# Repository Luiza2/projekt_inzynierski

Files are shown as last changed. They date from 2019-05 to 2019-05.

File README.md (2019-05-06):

Postępy realizacji pracy inżynierskiej.
Temat: Prędkościomierz z GPS i układem akwizycji danych.

Wykorzystane elementy:
- STM32 NUCLEO-F446RE
- wyświetlacz OLED niebieski graficzny 1,3'' 128x64px SPI
- moduł GPS NEO-7M-C (B) 
- moduł czytnika kart microSD
- moduł bluetooth HC-05
- własna płytka PCB (w opracowaniu)

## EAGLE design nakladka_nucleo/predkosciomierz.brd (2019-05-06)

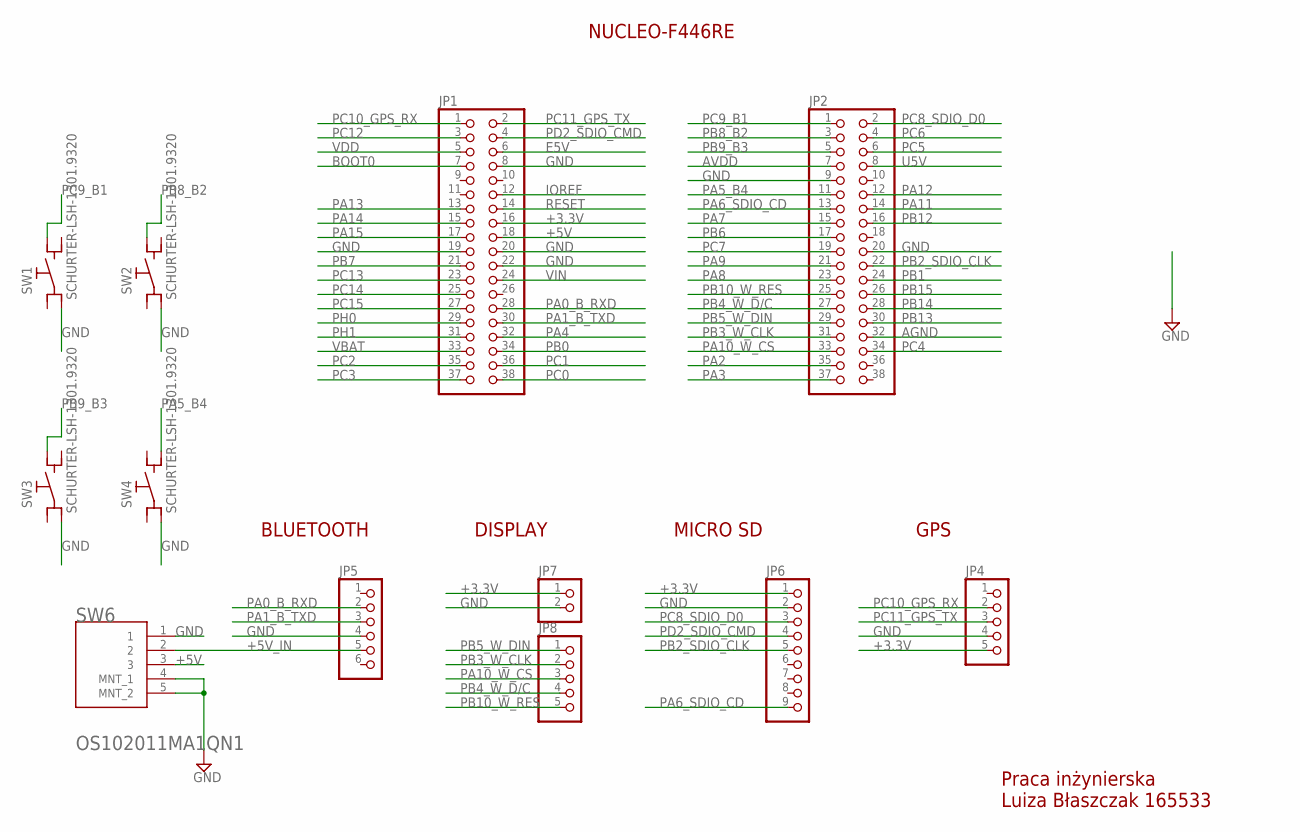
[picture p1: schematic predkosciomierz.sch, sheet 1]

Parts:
JP1, JP2: PINHD-2X19; 2X19
JP4, JP8: PINHD-1X5; 1X05
JP5: PINHD-1X6; 1X06
JP6: PINHD-1X9; 1X09
JP7: PINHD-1X2; 1X02
SW1, SW2, SW3, SW4: SCHURTER-LSH-1301.9320; LSH
SW6: C&K_OS102011MA1QN1C&K_OS102011MA1QN1_0_0; C&K_OS102011MA1QN1_0

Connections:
+3.3V: JP1.16, JP4.5, JP6.1, JP7.1
+5V: JP1.18, SW6.3
+5V_IN: JP5.5, SW6.2
AGND: JP2.32
AVDD: JP2.7
BOOT0: JP1.7
E5V: JP1.6; also elsewhere on the board
GND: JP1.8, JP1.19, JP1.20, JP1.22, JP2.9, JP2.20, JP4.4, JP5.4, JP6.2, JP7.2, SW1.C2 (C), SW2.C2 (C), SW3.C2 (C), SW4.C2 (C), SW6.1, SW6.4 (MNT_1), SW6.5 (MNT_2); also elsewhere on the board
IOREF: JP1.12
PA0_B_RXD: JP1.28, JP5.2
PA1_B_TXD: JP1.30, JP5.3
PA2: JP2.35
PA3: JP2.37
PA4: JP1.32
PA5_B4: JP2.11, SW4.NO2 (NO)
PA6_SDIO_CD: JP2.13, JP6.9
PA7: JP2.15
PA8: JP2.23
PA9: JP2.21
PA10_W_CS: JP2.33, JP8.3
PA11: JP2.14
PA12: JP2.12
PA13: JP1.13
PA14: JP1.15
PA15: JP1.17
PB0: JP1.34
PB1: JP2.24
PB2_SDIO_CLK: JP2.22, JP6.5
PB3_W_CLK: JP2.31, JP8.2
PB4_W_D/C: JP2.27, JP8.4
PB5_W_DIN: JP2.29, JP8.1
PB6: JP2.17
PB7: JP1.21
PB8_B2: JP2.3, SW2.NO1 (NO)
PB9_B3: JP2.5, SW3.NO1 (NO)
PB10_W_RES: JP2.25, JP8.5
PB12: JP2.16
PB13: JP2.30
PB14: JP2.28
PB15: JP2.26
PC0: JP1.38
PC1: JP1.36
PC2: JP1.35
PC3: JP1.37
PC4: JP2.34
PC5: JP2.6
PC6: JP2.4
PC7: JP2.19
PC8_SDIO_D0: JP2.2, JP6.3
PC9_B1: JP2.1, SW1.NO1 (NO)
PC10_GPS_RX: JP1.1, JP4.2
PC11_GPS_TX: JP1.2, JP4.3
PC12: JP1.3
PC13: JP1.23
PC14: JP1.25
PC15: JP1.27
PD2_SDIO_CMD: JP1.4, JP6.4
PH0: JP1.29
PH1: JP1.31
RESET: JP1.14
U5V: JP2.8
VBAT: JP1.33
VDD: JP1.5
VIN: JP1.24

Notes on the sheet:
DISPLAY
MICRO SD
GPS
NUCLEO-F446RE
BLUETOOTH
Praca inżynierska Luiza Błaszczak 165533

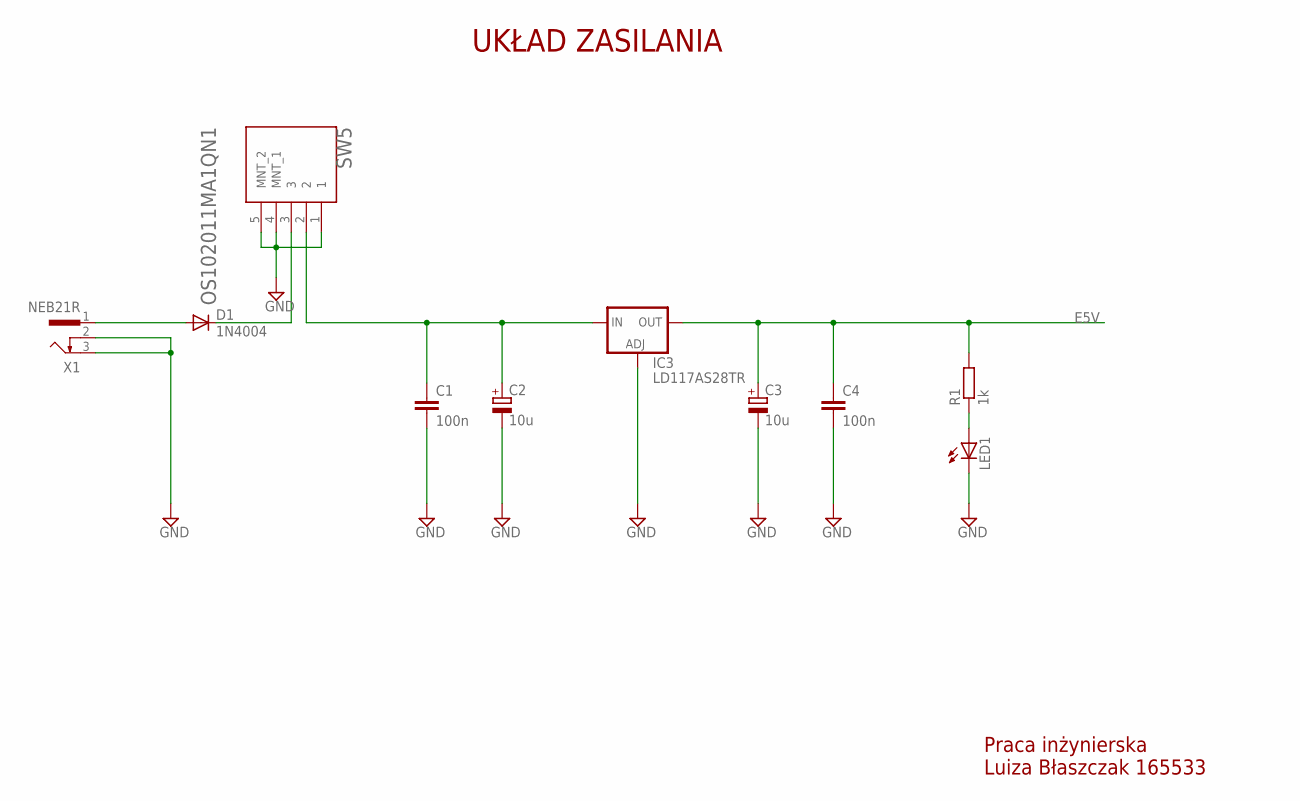
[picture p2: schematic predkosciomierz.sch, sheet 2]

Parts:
C1, C4: 100n; C1210
C2, C3: 10u; E2-5
D1: 1N4004; DO41-10
IC3: LD117AS28TR; SOT223
LED1: LED5MM
R1: 1k; 0204/7
SW5: C&K_OS102011MA1QN1C&K_OS102011MA1QN1_0_0; C&K_OS102011MA1QN1_0
X1: NEB21R

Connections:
E5V: C3.+, C4.1, IC3.4 (OUT), R1.2; also elsewhere on the board
GND: C1.2, C2.-, C3.-, C4.2, IC3.1 (ADJ), LED1.K (C), SW5.1, SW5.4 (MNT_1), SW5.5 (MNT_2), X1.2, X1.3; also elsewhere on the board
unnamed: LED1.A, R1.1
unnamed: C1.1, C2.+, IC3.3 (IN), SW5.2
unnamed: D1.C, SW5.3
unnamed: D1.A, X1.1

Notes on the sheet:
Praca inżynierska Luiza Błaszczak 165533
UKŁAD ZASILANIA

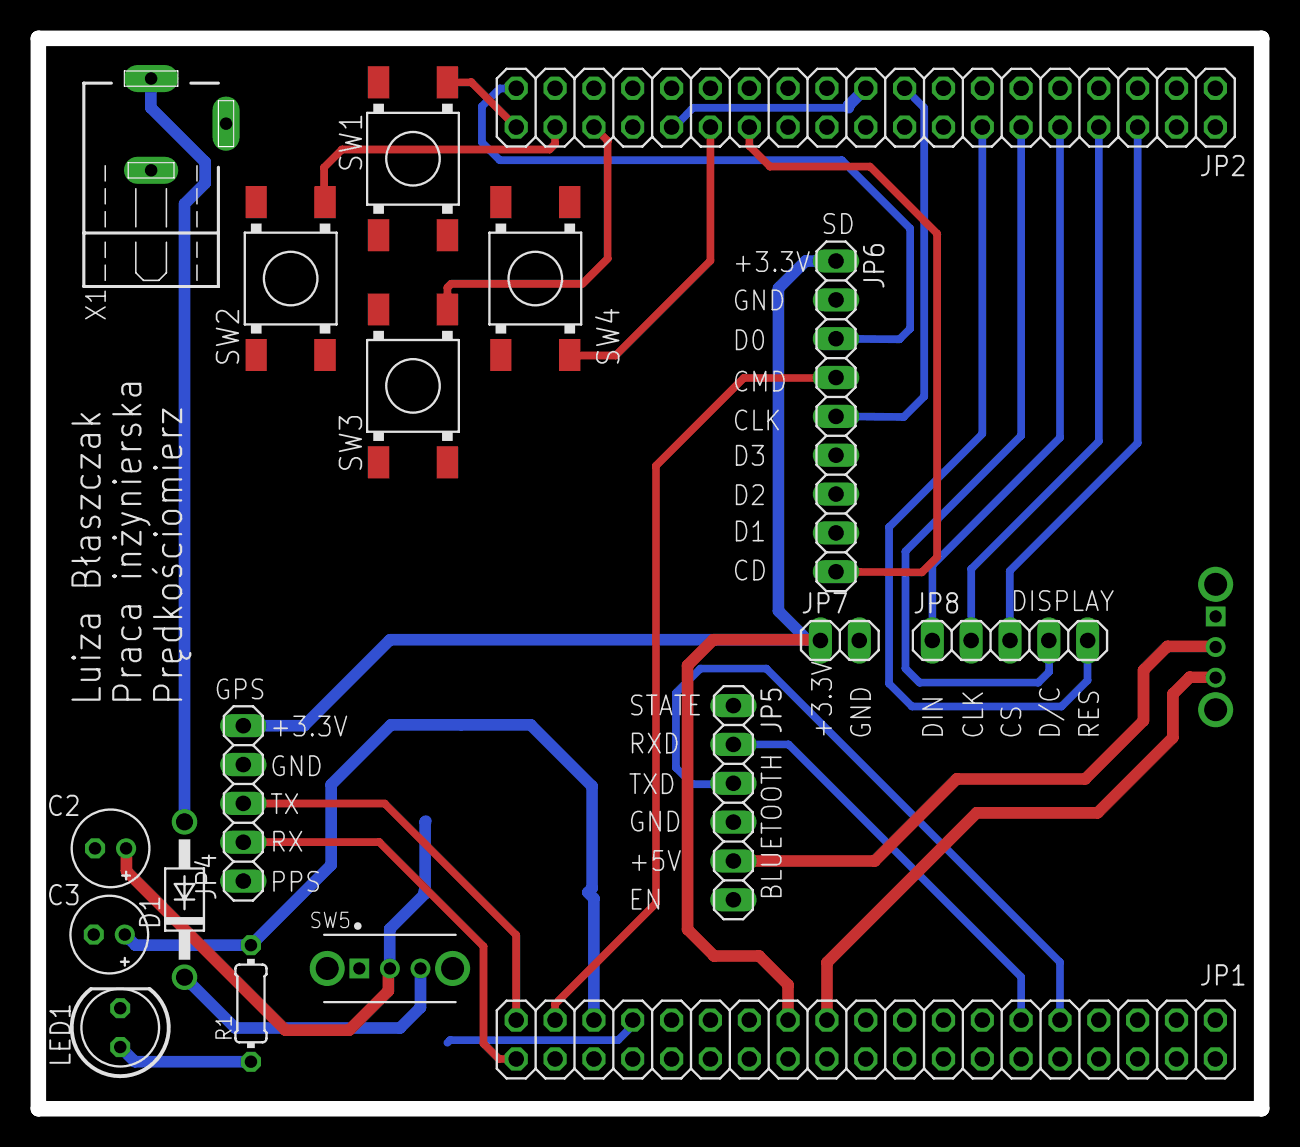
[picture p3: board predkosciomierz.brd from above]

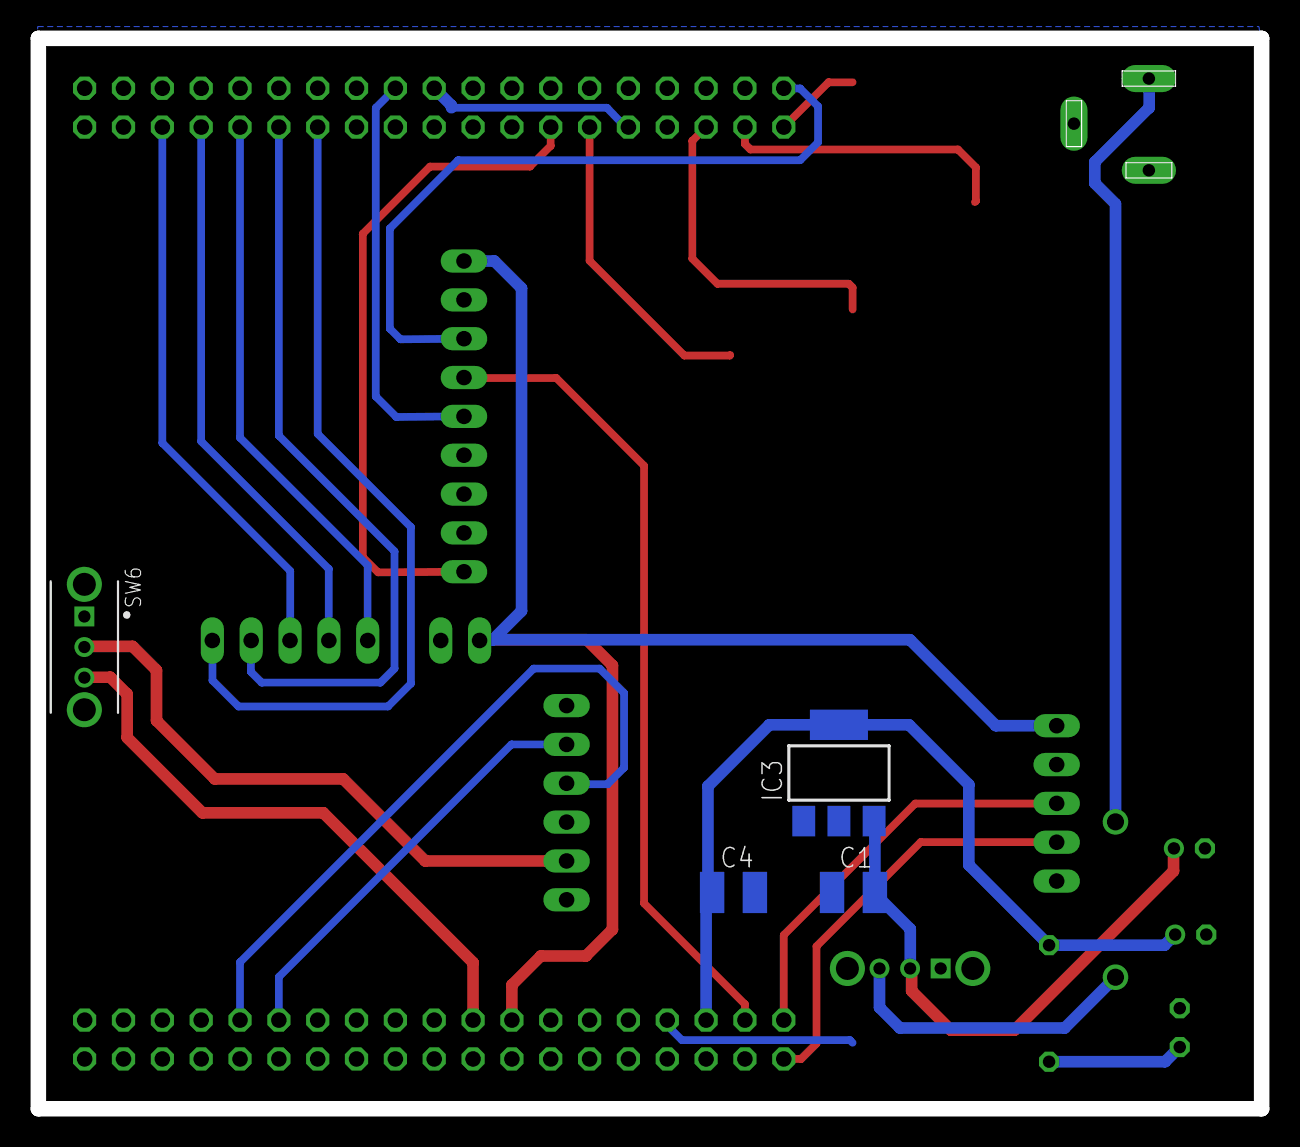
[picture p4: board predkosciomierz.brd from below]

Board: 2 copper layers, 80.0 x 70.0 mm, 22 parts (4 on the bottom side), 26 nets.

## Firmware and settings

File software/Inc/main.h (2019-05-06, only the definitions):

#define B_RXD_Pin GPIO_PIN_0
#define B_RXD_GPIO_Port GPIOA
#define B_TXD_Pin GPIO_PIN_1
#define B_TXD_GPIO_Port GPIOA
#define B4_Pin GPIO_PIN_5
#define B4_GPIO_Port GPIOA
#define SDIO_CD_Pin GPIO_PIN_6
#define SDIO_CD_GPIO_Port GPIOA
#define W_RES_Pin GPIO_PIN_10
#define W_RES_GPIO_Port GPIOB
#define B1_Pin GPIO_PIN_9
#define B1_GPIO_Port GPIOC
#define W_CS_Pin GPIO_PIN_10
#define W_CS_GPIO_Port GPIOA
#define GPS_RX_Pin GPIO_PIN_10
#define GPS_RX_GPIO_Port GPIOC
#define GPS_TX_Pin GPIO_PIN_11
#define GPS_TX_GPIO_Port GPIOC
#define W_CLK_Pin GPIO_PIN_3
#define W_CLK_GPIO_Port GPIOB
#define W_D_C_Pin GPIO_PIN_4
#define W_D_C_GPIO_Port GPIOB
#define W_DIN_Pin GPIO_PIN_5
#define W_DIN_GPIO_Port GPIOB
#define B2_Pin GPIO_PIN_8
#define B2_GPIO_Port GPIOB
#define B3_Pin GPIO_PIN_9
#define B3_GPIO_Port GPIOB

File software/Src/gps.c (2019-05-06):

#include "gps.h"

struct gps_state gps_init(UART_HandleTypeDef * uart) {
	struct gps_state state;

	state.uart = uart;
	for(uint8_t i=0; i<100; i++) state.line_buffer[i] = '\0';
	state.writer_position = 0;
	state.reader_position = 0;
	for(uint8_t i=0; i<30; i++) state.field_buffer[i] = '\0';
	state.field_position = 0;

	state.date_day = 0;
	state.date_mounth = 0;
	state.date_year = 0;
	state.time_hour = 0;
	state.time_min = 0;
	state.time_sec = 0;

	state.latitude = 0.0;
	state.latitude_direction = '?';
	state.longitude = 0.0;
	state.longitude_direction = '?';
	state.altitude = 0.0;

	state.speed_knots = 0.0;
	state.speed_kilometers = 0.0;

	state.satelites_number = 0;
	state.quality = '?';
	state.dop = 0.0;
	state.hdop = 0.0;
	state.vdop = 0.0;

	return state;
}

//zapisuje znaki do bufora
void gps_recv_char(struct gps_state * state, uint8_t recv_char) {
	if (state->writer_position == 0 && recv_char == '$') {
		state->writer_position++;
	} else if (state->writer_position >= 1 && state->writer_position < 99) {
		if (recv_char == '\r' || recv_char == '\n') {
			state->line_buffer[state->writer_position - 1] = '\0';
			state->writer_position = 0;
			gps_process_line(state);
		} else {
			//kolejne znaki zapisywane na kolejnych pozycjach bufora
			state->line_buffer[state->writer_position - 1] = recv_char;
			state->writer_position++;
		}
	} else {
		state->writer_position = 0;
	}
}

//odczytuje pola po znaku przecinka lub konca ciagu
void gps_read_field(struct gps_state * state) {
	state->field_position = 0;
	while(state->line_buffer[state->reader_position] != ',' && state->line_buffer[state->reader_position] != '\0'
			&& state->field_position < 29) {
		state->field_buffer[state->field_position] = state->line_buffer[state->reader_position];
		state->reader_position++;
		state->field_position++;
	}
	state->field_buffer[state->field_position] = '\0';
	state->reader_position++;
}

//odczytuje typ ramki danych i wywoluje odpowiednia funkcje ja przetwarzajaca
void gps_process_line(struct gps_state * state) {
	state->reader_position = 0;
	gps_read_field(state);
	     if(strcmp(state->field_buffer, "GPRMC") == 0) gps_process_gprmc(state);
	else if(strcmp(state->field_buffer, "GPVTG") == 0) gps_process_gpvtg(state);
	else if(strcmp(state->field_buffer, "GPGGA") == 0) gps_process_gpgga(state);
	else if(strcmp(state->field_buffer, "GPGSA") == 0) gps_process_gpgsa(state);
}

void gps_process_gprmc(struct gps_state * state)
{
	//$GPRMC,212846.00,A,5025.81511,N,01639.92090,E,0.196,,140417,,,A*73
	gps_read_field(state);
	if(strlen(state->field_buffer) > 0) {
		uint32_t tmp;
		sscanf(state->field_buffer, "%d", &tmp);
		state->time_sec = tmp % 100;
		state->time_min = (tmp / 100) % 100;
		state->time_hour = (tmp / 10000) % 100; //utc
	}

	gps_read_field(state);

	gps_read_field(state);
	if(strlen(state->field_buffer) > 0) sscanf(state->field_buffer, "%lf", &(state->latitude));

	gps_read_field(state);
	if(strlen(state->field_buffer) > 0) sscanf(state->field_buffer, "%c", &(state->latitude_direction));

	gps_read_field(state);
	if(strlen(state->field_buffer) > 0) sscanf(state->field_buffer, "%lf", &(state->longitude));

	gps_read_field(state);
	if(strlen(state->field_buffer) > 0) sscanf(state->field_buffer, "%c", &(state->longitude_direction));

	gps_read_field(state);
	gps_read_field(state);

	gps_read_field(state);
	if(strlen(state->field_buffer) > 0) {
		uint32_t tmp;
		sscanf(state->field_buffer, "%d", &tmp);
		state->date_year = tmp % 100;
		state->date_mounth = (tmp / 100) % 100;
		state->date_day = (tmp / 10000) % 100;
	}
}

void gps_process_gpvtg(struct gps_state * state)
{
	//$GPVTG,,T,,M,0.196,N,0.363,K,A*2B
	gps_read_field(state);
	gps_read_field(state);
	gps_read_field(state);
	gps_read_field(state);

	gps_read_field(state);
	if(strlen(state->field_buffer) > 0) sscanf(state->field_buffer, "%lf", &(state->speed_knots));

	gps_read_field(state);

	gps_read_field(state);
	if(strlen(state->field_buffer) > 0) sscanf(state->field_buffer, "%lf", &(state->speed_kilometers));
}

void gps_process_gpgga(struct gps_state * state)
{
	//$GPGGA,212846.00,5025.81511,N,01639.92090,E,1,04,4.72,281.1,M,42.0,M,,*5F
	gps_read_field(state);
	gps_read_field(state);
	gps_read_field(state);
	gps_read_field(state);
	gps_read_field(state);

	gps_read_field(state);
	if(strlen(state->field_buffer) > 0) sscanf(state->field_buffer, "%d", &(state->quality));

	gps_read_field(state);
	if(strlen(state->field_buffer) > 0) sscanf(state->field_buffer, "%d", &(state->satelites_number));

	gps_read_field(state);

	gps_read_field(state);
	if(strlen(state->field_buffer) > 0) sscanf(state->field_buffer, "%lf", &(state->altitude));
}

void gps_process_gpgsa(struct gps_state * state)
{
	//$GPGSA,A,3,10,18,21,15,,,,,,,,,6.79,4.72,4.89*01
	gps_read_field(state);
	gps_read_field(state);
	gps_read_field(state);
	gps_read_field(state);
	gps_read_field(state);
	gps_read_field(state);
	gps_read_field(state);
	gps_read_field(state);
	gps_read_field(state);
	gps_read_field(state);
	gps_read_field(state);
	gps_read_field(state);
	gps_read_field(state);
	gps_read_field(state);

	gps_read_field(state);
	if(strlen(state->field_buffer) > 0) sscanf(state->field_buffer, "%lf", &(state->dop));

	gps_read_field(state);
	if(strlen(state->field_buffer) > 0) sscanf(state->field_buffer, "%lf", &(state->hdop));

	gps_read_field(state);
	if(strlen(state->field_buffer) > 0) sscanf(state->field_buffer, "%lf", &(state->vdop));
}

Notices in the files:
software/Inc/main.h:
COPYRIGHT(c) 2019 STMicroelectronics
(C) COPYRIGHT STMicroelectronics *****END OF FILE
